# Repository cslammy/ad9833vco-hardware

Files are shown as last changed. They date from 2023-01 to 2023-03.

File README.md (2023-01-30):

# ad9833vco-hardware
Schematics, eagle files etc for AD9833 VCO

I have an ongoing project--building a volt octave VCO using the AD9833 function generator IC.  This repo has current zips of Eagle files, BOMs, gerbers, and PDFs of boards and schematics.

What I post here (1-30-23) works on my bench but could stand some improvement in terms of frequency stability and generally improving the triangle to ramp conversion. The rest of it seems to work. I will update the zips here as I continue to improve this design...

Blog post (which links other posts about this project) is here.
https://audiodiwhy.blogspot.com/2023/01/ad9833-audio-vco-works-work-in-progress.html

Embedded C for this project can be found in this repo: AD9833-VCO

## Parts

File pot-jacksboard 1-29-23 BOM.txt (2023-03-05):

 unt9833VCO pots jacks 1-29-23.sch 

Part       Value         Device                   Package            Description                                       POPULARITY SPICEPREFIX
                    
EUROPWR                  EURO_POWER_HEADERREGULAR EURO_POWER_HEADER  Power Header                                                            
FINE       50K           9MM_SNAP-IN_POT_         9MM_SNAP-IN_POT    9mm vertical snap-in pot, Alpha / Panasonic style                       
FREQ       100k          9MM_SNAP-IN_POT_         9MM_SNAP-IN_POT    9mm vertical snap-in pot, Alpha / Panasonic style                       
                     
MODIN\     THONKICONNNEW THONKICONNNEW            WQP-PJ301M-12_JACK 3.5mm socket for Eurorack modular synths                                
MODLEV     100K          9MM_SNAP-IN_POT_         9MM_SNAP-IN_POT    9mm vertical snap-in pot, Alpha / Panasonic style                       
                
PULSEOUT   THONKICONNNEW THONKICONNNEW            WQP-PJ301M-12_JACK 3.5mm socket for Eurorack modular synths                                
PW-INITIAL 100k          9MM_SNAP-IN_POT_         9MM_SNAP-IN_POT    9mm vertical snap-in pot, Alpha / Panasonic style                       
PWM        100k          9MM_SNAP-IN_POT_         9MM_SNAP-IN_POT    9mm vertical snap-in pot, Alpha / Panasonic style                       
PWMIN      THONKICONNNEW THONKICONNNEW            WQP-PJ301M-12_JACK 3.5mm socket for Eurorack modular synths                                
R1         100K          R-US_0204/7              0204/7             RESISTOR, American symbol                         48         R          
R2         100K          R-US_0207/15             0207/15            RESISTOR, American symbol                         0          R          
R3         100K          R-US_0207/15             0207/15            RESISTOR, American symbol                         0          R          
R4         100ohms       R-US_0207/15             0207/15            RESISTOR, American symbol                         0          R          
R5         100ohms       R-US_0207/15             0207/15            RESISTOR, American symbol                         0          R          
R6         100K          R-US_0207/15             0207/15            RESISTOR, American symbol                         0          R          
R7         100K          R-US_0204/7              0204/7             RESISTOR, American symbol                         48         R          
R8         470K          R-US_0204/7              0204/7             RESISTOR, American symbol                         48         R          
R9         470K          R-US_0204/7              0204/7             RESISTOR, American symbol                         48         R          
RAMPOUT    THONKICONNNEW THONKICONNNEW            WQP-PJ301M-12_JACK 3.5mm socket for Eurorack modular synths                                
                    
TRIOUT     THONKICONNNEW THONKICONNNEW            WQP-PJ301M-12_JACK 3.5mm socket for Eurorack modular synths                                
                  
VOCT       THONKICONNNEW THONKICONNNEW            WQP-PJ301M-12_JACK 3.5mm socket for Eurorack modular synths     

For hardware You will need 100mil (2.54mm) male and female PCB edge connectors
Male: Amphenol 	10129378-920003BLF (get 40 pin edge connector and cut apart what you need)
Female: Adafruit 36-PIN 0.1 FEMALE HEADER- 5PK (digikey 1528-2537-ND)

Also 4/40 phillips screws (I used 3/4" Pan Phillips but most anything about this size will work) with nuts and washers to secure daughterboards to this PCB)

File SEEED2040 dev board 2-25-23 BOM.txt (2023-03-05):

seeed2040 dev board 11-13-22.sch BOM for AD9833 VCO

ADC    MCP3201-CI/P      MCP3201-CI/P      DIP787W46P254L927H533Q8    1-Channel Single ADC SAR 100ksps 12-bit Serial Automotive 8-Pin PDIP Tube  Microchip Technology MCP3201-CI/P DIP-8 Microchip                                                               
C1     .47uF             C-US025-030X050   C025-030X050            CAPACITOR, American symbol                                                                                                                                                                                                                                             C                                      
C4     1nf               C-US025-025X050   C025-025X050            CAPACITOR, American symbol                                                                                                                                                                                                                                              C                                      
C5     .1uF              C-US025-025X050   C025-025X050            CAPACITOR, American symbol                                                                                                                                                                                                                                           C                                      
C6     1nf               C-US025-025X050   C025-025X050            CAPACITOR, American symbol                                                                                                                                                                                                                                          C                                      
C7     1nf               C-US025-025X050   C025-025X050            CAPACITOR, American symbol                                                                                                                                                      
C8     1nf               C-US025-025X050   C025-025X050            CAPACITOR, American symbol                                                                                                                                                                                                                                             C                                      
C9     .1uF              C-US050-025X075   C050-025X075            CAPACITOR, American symbol                                                                                                                                                                                                                                                                                       
C10    .1uF              C-US025-025X050   C025-025X050            CAPACITOR, American symbol                                                                                                                                                                                                                                               C                                      
C11    10uF              CPOL-USE2.5-7     E2,5-7                  POLARIZED CAPACITOR, American symbol                                                                                                                                                                                                                                      C                                      
                                                                                                                                                                                                                                                                                 
D2     Zener 3.3V        ZENER.3           DO41-3                   zener diode                                                                                                                                                                                                                                                                                                                
                                                                                                                                                                                                                                                                                 
D3     10V               ZENER.3           DO41-3                   zener diode                                                                                                                                                                                                                                                                                                                
                                                                                                                                                                                                                                                                                 
IC1-5V L4931             L4931             TO92-                    Voltage regulator                                                                                                                                                                                                                                                                                                                
                                                                                                                                                                                                                                                                               
R1     150K**              R-US_0204/7       0204/7                  RESISTOR, American symbol                                                                                                                                                                                                                                                                                        
R2     150K**              R-US_0204/7       0204/7                  RESISTOR, American symbol                                                                                                                                                                                                                                                                                        
R3     33K**               R-US_0204/7       0204/7                  RESISTOR, American symbol                                                                                                                                                                                                                                                                                        
R4     150K**              R-US_0204/7       0204/7                  RESISTOR, American symbol                                                                                                                                                                                                                                                                                        
R5     100K              R-US_0204/7       0204/7                  RESISTOR, American symbol                                                                                                                                                                                                                                                                                        
R6     33K               R-US_0204/7       0204/7                  RESISTOR, American symbol                                                                                                                                                                                                                                                                                        
R7     1.2K              R-US_0204/7       0204/7                  RESISTOR, American symbol                                                                                                                                                                                                                                                                                        
R8     47K               R-US_0204/7       0204/7                  RESISTOR, American symbol                                                                                                                                                                                                                                                                                        
R9     33K**               R-US_0204/7       0204/7                  RESISTOR, American symbol                                                                                                                                                                                                                                                                                        
R10    100K*              R-US_0204/7       0204/7                  RESISTOR, American symbol                                                                                                                                                                                                                                                                                        
R11    100K*              R-US_0204/7       0204/7                  RESISTOR, American symbol                                                                                                                                                                                                                                                                                        
R12    100K*              R-US_0204/7       0204/7                  RESISTOR, American symbol                                                                                                                                                                                                                                                                                        
R13    33K**               R-US_0204/7       0204/7                  RESISTOR, American symbol                                                                                                                                                                                                                                                                                        
R14    2701%             R-US_0204/7       0204/7                  RESISTOR, American symbol                                                                                                                                                                                                                                              
NOTES on resistors for AD9833 build:
* you can use any resistor value here--or a jumper wire.                                          
** this resistor is not needed for AD9833 build (since given op amp stage has both inputs grounded)--you can omit this resistor if you are using this buffer to build an RP2040-AD9833 audio volt/octave VCO
                                                                                                                                                                                                                                                                                 
SEEDY1 SEEED_XIAO_RP2040 SEEED_XIAO_RP2040 14PIN700MIL             RP2040 Development board                                                                                                                                                                                                                                                                                                                    
T1     50K               R-TRIMMT93YA      RTRIMT93YA              Trimm resistor                                                              
                                                                                                                                                                                               
U1     MCP6004-DIP       MCP6004-DIP       DIL14                   MCP6004 RAIL TO RAIL QUAD OP AMP

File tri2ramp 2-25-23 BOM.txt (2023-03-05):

 
tri to ramp-pls 2-25-23.sch 

Part    Value   Device          Package       Description                          POPULARITY SPICEPREFIX
        1                     
C1      2.2uF   CPOL-USE5-4     E5-4          POLARIZED CAPACITOR, American symbol                       
C2      .0022uF C-US050-030X075 C050-030X075  CAPACITOR, American symbol           5          C          
C3      .0022uF C-US050-035X075 C050-035X075  CAPACITOR, American symbol           0          C          
C4      .1uF    C-US025-025X050 C025-025X050  CAPACITOR, American symbol           0          C          
C5      .1uF    C-US025-025X050 C025-025X050  CAPACITOR, American symbol           0          C          
C6      .1uF    C-US025-025X050 C025-025X050  CAPACITOR, American symbol           0          C          
C7      .1uF    C-US025-025X050 C025-025X050  CAPACITOR, American symbol           0          C          
C8      10uF    CPOL-USE5-4     E5-4          POLARIZED CAPACITOR, American symbol                       
C9      .01uF   C-US050-035X075 C050-035X075  CAPACITOR, American symbol           0          C          
D1      5V      ZENER.3         DO41-3        3V Zener                                                           
                  
IC1     TL084D  TL084D          SO14          OP AMP                               4                     
IC2     CA3140N CA3140N         DIL08         OP AMP                               3                     
IC3     TL081D  TL081D          SO08          OP AMP                                                     
IC4     7805L   ADAFRUIT_7805L  ADAFRUIT_TO92 Positive VOLTAGE REGULATOR                                 
         1                     
Q1      2N7000  2N7000          TO92-         MOSFET                                                          
R1      10K 1%  R-US_0204/7     0204/7        RESISTOR, American symbol                                  
R2      27K     R-US_0204/7     0204/7        RESISTOR, American symbol                                  
R3      20K     R-US_0204/7     0204/7        RESISTOR, American symbol                                  
R4      20K     R-US_0204/7     0204/7        RESISTOR, American symbol                                  
R5      200K    R-US_0204/7     0204/7        RESISTOR, American symbol                                  
R6      1K      R-US_0204/7     0204/7        RESISTOR, American symbol                                  
R7      1K      R-US_0204/7     0204/7        RESISTOR, American symbol                                  
R8      100K    R-US_0204/7     0204/7        RESISTOR, American symbol                                  
R9      100K    R-US_0204/7     0204/7        RESISTOR, American symbol                                  
R10     100K    R-US_0204/7     0204/7        RESISTOR, American symbol                                  
R11     20K     R-US_0204/7     0204/7        RESISTOR, American symbol                                  
R12     1K      R-US_0204/7     0204/7        RESISTOR, American symbol                                  
R13     180     R-US_0204/7     0204/7        RESISTOR, American symbol                                  
R14     1K      R-US_0204/7     0204/7        RESISTOR, American symbol                                  
R15     10K     R-US_0204/7     0204/7        RESISTOR, American symbol                                  
R16     20K 1%  R-US_0204/7     0204/7        RESISTOR, American symbol                                  
R17     100K 1% R-US_0204/7     0204/7        RESISTOR, American symbol                                  
R18     50K 1%  R-US_0204/7     0204/7        RESISTOR, American symbol                                  
R19     20K     R-US_0204/7     0204/7        RESISTOR, American symbol                                  

Breakout Board:
Project requires AD9833 Sig Generator with the following pinout:
VCC
DGND
SDATA
SCLK
FSYNC
AGND
OUT

here is one that works (the one I used)
NOYITO AD9833 Programmable Microprocessor Serial Interface Module Sine Square Wave DDS Signal Generator
https://www.amazon.com/NOYITO-Programmable-Microprocessor-Interface-Generator/dp/B07HFRFMPM
There are many other vendors selling boards just like this on Aliexpress, Ebay etc.
But!! Check to make sure what you buy has the pinout above.

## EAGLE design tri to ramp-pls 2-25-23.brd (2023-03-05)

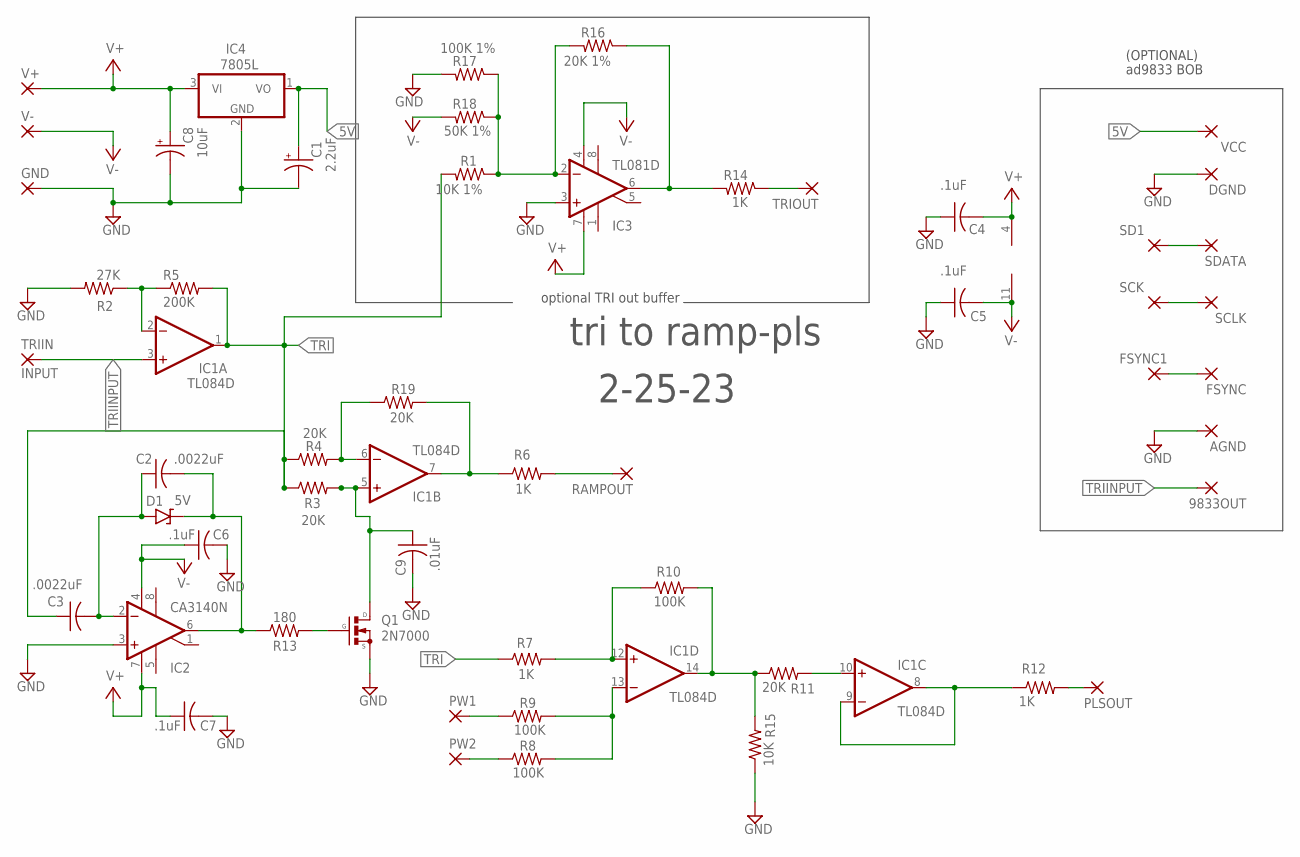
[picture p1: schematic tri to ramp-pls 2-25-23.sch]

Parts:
9833OUT: WIREPAD1,6/0,8; 1,6/0,8
AGND: WIREPAD1,6/0,8; 1,6/0,8
C1: 2.2uF; E5-4
C2: .0022uF; C050-030X075
C3: .0022uF; C050-035X075
C4, C5, C6, C7: .1uF; C025-025X050
C8: 10uF; E5-4
C9: .01uF; C050-035X075
D1: 5V; DO41-3
DGND: WIREPAD1,6/0,8; 1,6/0,8
FSYNC, FSYNC1: WIREPAD1,6/0,8; 1,6/0,8
GND: WIREPAD1,6/0,8; 1,6/0,8
IC1: TL084D; SO14
IC2: CA3140N; DIL08
IC3: TL081D; SO08
IC4: 7805L; ADAFRUIT_TO92
PLSOUT: WIREPAD1,6/0,8; 1,6/0,8
PW1, PW2: WIREPAD1,6/0,8; 1,6/0,8
Q1: 2N7000; TO92-
R1: 10K 1%; 0204/7
R2: 27K; 0204/7
R3, R4, R11, R19: 20K; 0204/7
R5: 200K; 0204/7
R6, R7, R12, R14: 1K; 0204/7
R8, R9, R10: 100K; 0204/7
R13: 180; 0204/7
R15: 10K; 0204/7
R16: 20K 1%; 0204/7
R17: 100K 1%; 0204/7
R18: 50K 1%; 0204/7
RAMPOUT: WIREPAD1,6/0,8; 1,6/0,8
SCK: WIREPAD1,6/0,8; 1,6/0,8
SCLK: WIREPAD1,6/0,8; 1,6/0,8
SD1: WIREPAD1,6/0,8; 1,6/0,8
SDATA: WIREPAD1,6/0,8; 1,6/0,8
TRIIN: INPUT; 1,6/0,8
TRIOUT: WIREPAD1,6/0,8; 1,6/0,8
V+: WIREPAD1,6/0,8; 1,6/0,8
V-: WIREPAD1,6/0,8; 1,6/0,8
VCC: WIREPAD1,6/0,8; 1,6/0,8

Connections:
5V: C1.+, IC4.1 (VO), VCC.1
GND: AGND.1, C1.-, C4.1, C5.1, C6.2, C7.2, C8.-, C9.2, DGND.1, GND.1, IC2.3 (+IN), IC3.3 (+IN), IC4.2 (GND), Q1.3 (S), R2.2, R15.1, R17.2
unnamed: IC1.2 (-IN), R2.1, R5.1
unnamed: PW1.1, R9.1
unnamed: SD1.1, SDATA.1
unnamed: IC1.12 (+IN), R7.2, R10.1
unnamed: IC1.6 (-IN), R4.2, R19.1
unnamed: C9.1, IC1.5 (+IN), Q1.1 (D), R3.2
unnamed: C2.1, C3.2, D1.A, IC2.2 (-IN)
unnamed: IC1.7 (OUT), R6.1, R19.2
unnamed: C2.2, D1.C, IC2.6 (OUT), R13.1
unnamed: Q1.2 (G), R13.2
unnamed: IC1.14 (OUT), R10.2, R11.1, R15.2
unnamed: R6.2, RAMPOUT.1
unnamed: IC1.10 (+IN), R11.2
unnamed: IC1.8 (OUT), IC1.9 (-IN), R12.1
unnamed: PLSOUT.1, R12.2
unnamed: IC1.13 (-IN), R8.2, R9.2
unnamed: IC3.2 (-IN), R1.1, R16.2, R17.1, R18.1
unnamed: PW2.1, R8.1
unnamed: R14.1, TRIOUT.1
unnamed: SCK.1, SCLK.1
unnamed: FSYNC.1, FSYNC1.1
unnamed: IC3.6 (OUT), R14.2, R16.1
TRI: C3.1, IC1.1 (OUT), R1.2, R3.1, R4.1, R5.2, R7.1
TRIINPUT: 9833OUT.1, IC1.3 (+IN), TRIIN.1
V+: C4.2, C7.1, C8.+, IC1.4 (V+), IC2.7 (V+), IC3.7 (V+), IC4.3 (VI), V+.1
V-: C5.2, C6.1, IC1.11 (V-), IC2.4 (V-), IC3.4 (V-), R18.2, V-.1

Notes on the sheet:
tri to ramp-pls
2-25-23
optional TRI out buffer
ad9833 BOB
(OPTIONAL)

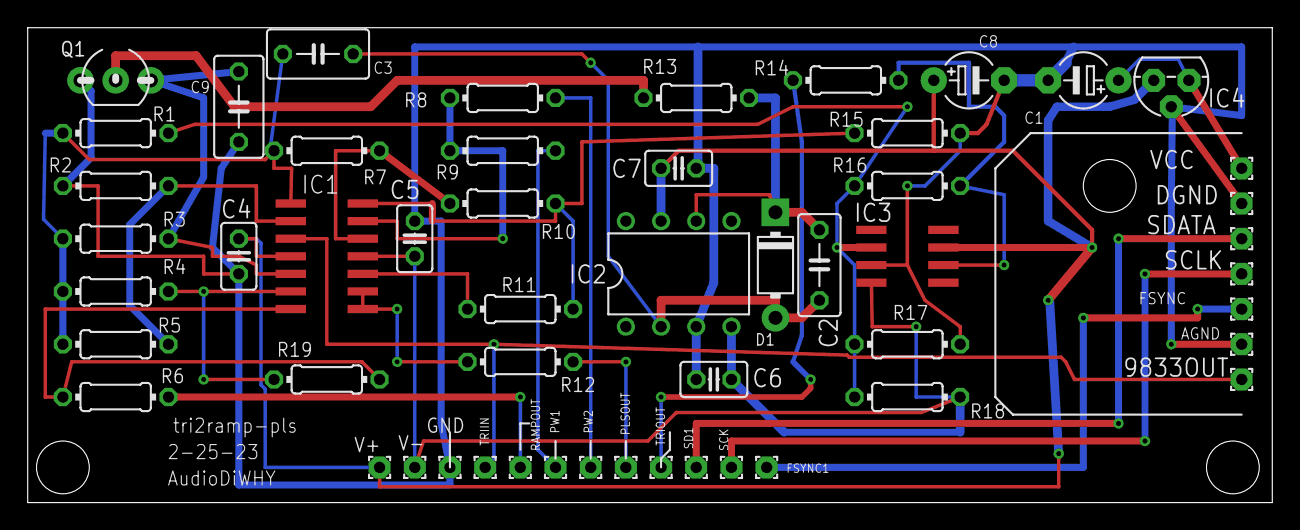
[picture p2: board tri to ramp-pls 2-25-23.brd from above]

Board: 2 copper layers, 89.8 x 34.3 mm, 53 parts (0 on the bottom side), 28 nets.

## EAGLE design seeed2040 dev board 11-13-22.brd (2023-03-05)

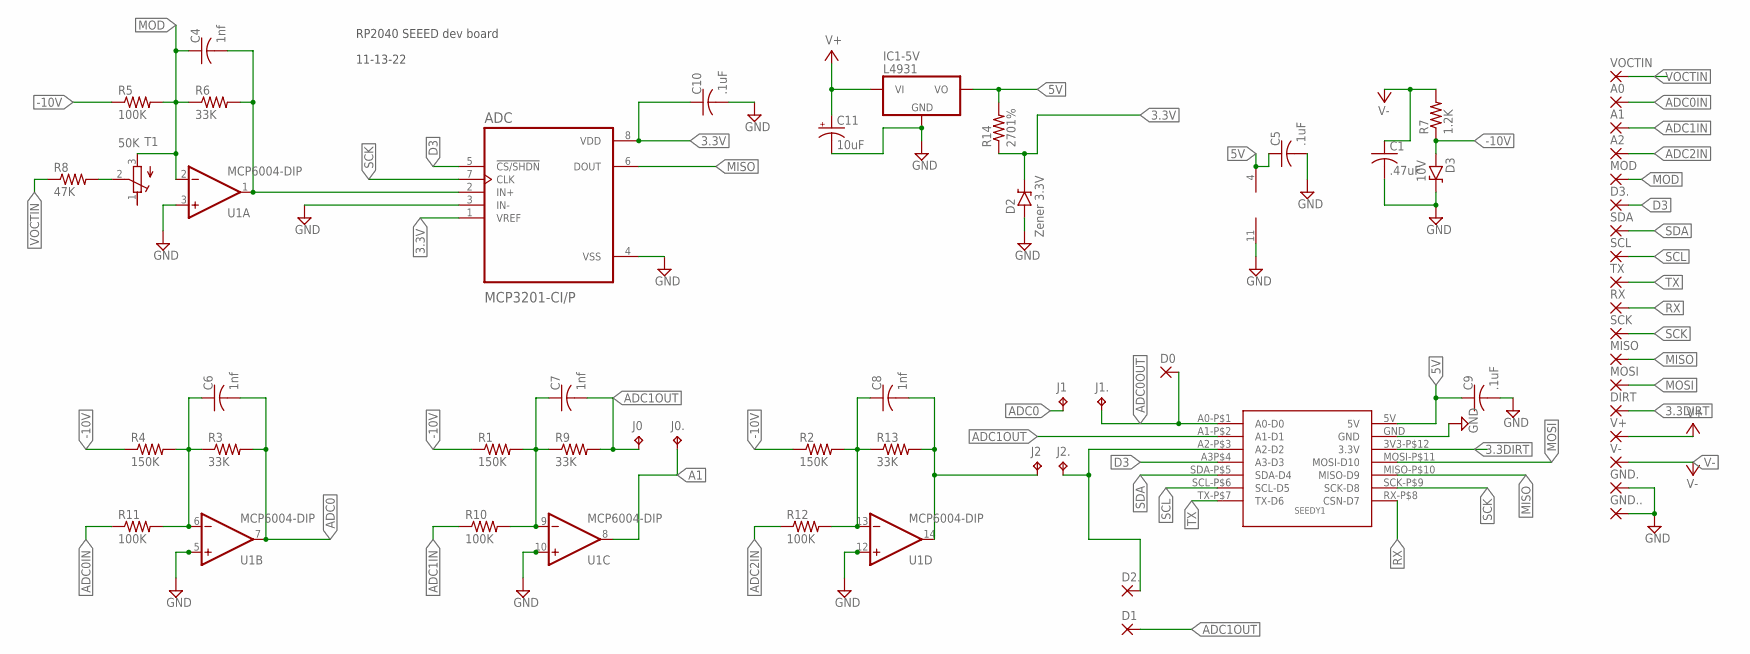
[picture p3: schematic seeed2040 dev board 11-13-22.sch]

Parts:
A0, A1, A2: WIREPAD1,6/0,9; 1,6/0,9
ADC: MCP3201-CI/P; DIP787W46P254L927H533Q8
C1: .47uF; C025-030X050
C4, C6, C7, C8: 1nf; C025-025X050
C5, C10: .1uF; C025-025X050
C9: .1uF; C050-025X075
C11: 10uF; E2,5-7
D0, D1, D2., D3.: WIREPAD1,6/0,9; 1,6/0,9
D2: Zener 3.3V; DO41-3
D3: 10V; DO41-3
DIRT: WIREPAD1,6/0,9; 1,6/0,9
GND., GND..: WIREPAD1,6/0,9; 1,6/0,9
IC1-5V: L4931; TO92-
J0, J0., J1, J1., J2, J2.: TPPAD1-13; P1-13
MISO: WIREPAD1,6/0,9; 1,6/0,9
MOD: WIREPAD1,6/0,9; 1,6/0,9
MOSI: WIREPAD1,6/0,9; 1,6/0,9
R1, R2, R4: 150K; 0204/7
R3, R6, R9, R13: 33K; 0204/7
R5, R10, R11, R12: 100K; 0204/7
R7: 1.2K; 0204/7
R8: 47K; 0204/7
R14: 2701%; 0204/7
RX: WIREPAD1,6/0,9; 1,6/0,9
SCK: WIREPAD1,6/0,9; 1,6/0,9
SCL: WIREPAD1,6/0,9; 1,6/0,9
SDA: WIREPAD1,6/0,9; 1,6/0,9
SEEDY1: SEEED_XIAO_RP2040; 14PIN700MIL
T1: 50K; RTRIMT93YA
TX: WIREPAD1,6/0,9; 1,6/0,9
U1: MCP6004-DIP; DIL14
V+: WIREPAD1,6/0,9; 1,6/0,9
V-: WIREPAD1,6/0,9; 1,6/0,9
VOCTIN: WIREPAD1,6/0,9; 1,6/0,9

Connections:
3.3DIRT: DIRT.1, SEEDY1.3V3-P$12 (3.3V)
3.3V: ADC.1 (VREF), ADC.8 (VDD), C10.1, D2.C, R14.1
5V: C5.1, C9.1, IC1-5V.3 (VO), R14.2, SEEDY1.5V, U1.4 (V+)
-10V: D3.A, R1.1, R2.1, R4.1, R5.1, R7.1
A1: J0..TP, U1.8 (OUT)
ADC0: C6.2, J1.TP, R3.2, U1.7 (OUT)
ADC0IN: A0.1, R11.1
ADC0OUT: D0.1, J1..TP, SEEDY1.A0-P$1 (A0-D0)
ADC1IN: A1.1, R10.1
ADC1OUT: C7.2, D1.1, J0.TP, R9.2, SEEDY1.A1-P$2 (A1-D1)
ADC2IN: A2.1, R12.1
ADC2OUT: C8.2, J2.TP, R13.2, U1.14 (OUT)
D3: ADC.5 (!CS/SHDN), D3..1, SEEDY1.A3P$4 (A3-D3)
GND: ADC.3 (IN-), ADC.4 (VSS), C1.2, C5.2, C9.2, C10.2, C11.-, D2.A, D3.C, GND..1, GND...1, IC1-5V.2 (GND), SEEDY1.GND, U1.3 (+IN), U1.5 (+IN), U1.10 (+IN), U1.11 (V-), U1.12 (+IN)
MISO: ADC.6 (DOUT), MISO.1, SEEDY1.MISO-P$10 (MISO-D9)
MOD: C4.1, MOD.1, R5.2, R6.1, T1.3 (A), U1.2 (-IN)
MOSI: MOSI.1, SEEDY1.MOSI-P$11 (MOSI-D10)
unnamed: C6.1, R3.1, R4.2, R11.2, U1.6 (-IN)
unnamed: C7.1, R1.2, R9.1, R10.2, U1.9 (-IN)
unnamed: R8.2, T1.2 (S)
unnamed: C8.1, R2.2, R12.2, R13.1, U1.13 (-IN)
unnamed: D2..1, J2..TP, SEEDY1.A2-P$3 (A2-D2)
RX: RX.1, SEEDY1.RX-P$8 (CSN-D7)
SCK: ADC.7 (CLK), SCK.1, SEEDY1.SCK-P$9 (SCK-D8)
SCL: SCL.1, SEEDY1.SCL-P$6 (SCL-D5)
SDA: SDA.1, SEEDY1.SDA-P$5 (SDA-D4)
TX: SEEDY1.TX-P$7 (TX-D6), TX.1
V+: C11.+, IC1-5V.1 (VI), V+.1
V-: C1.1, R7.2, V-.1
VOCTIN: R8.1, VOCTIN.1
VOCTOUT: ADC.2 (IN+), C4.2, R6.2, U1.1 (OUT)

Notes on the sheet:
RP2040 SEEED dev board
11-13-22

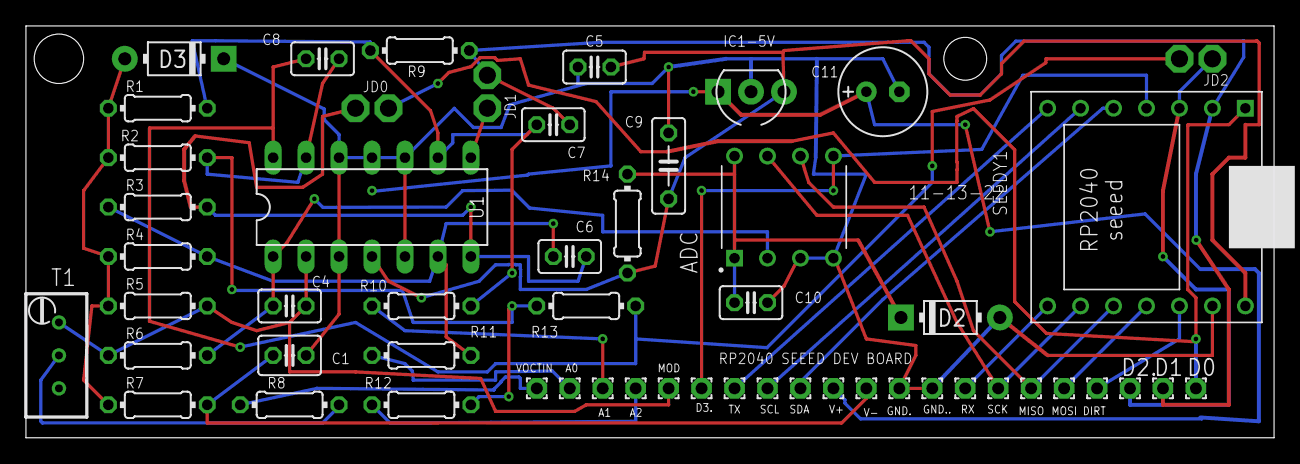
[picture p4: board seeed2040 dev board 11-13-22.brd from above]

Board: 2 copper layers, 96.2 x 31.7 mm, 57 parts (0 on the bottom side), 31 nets.

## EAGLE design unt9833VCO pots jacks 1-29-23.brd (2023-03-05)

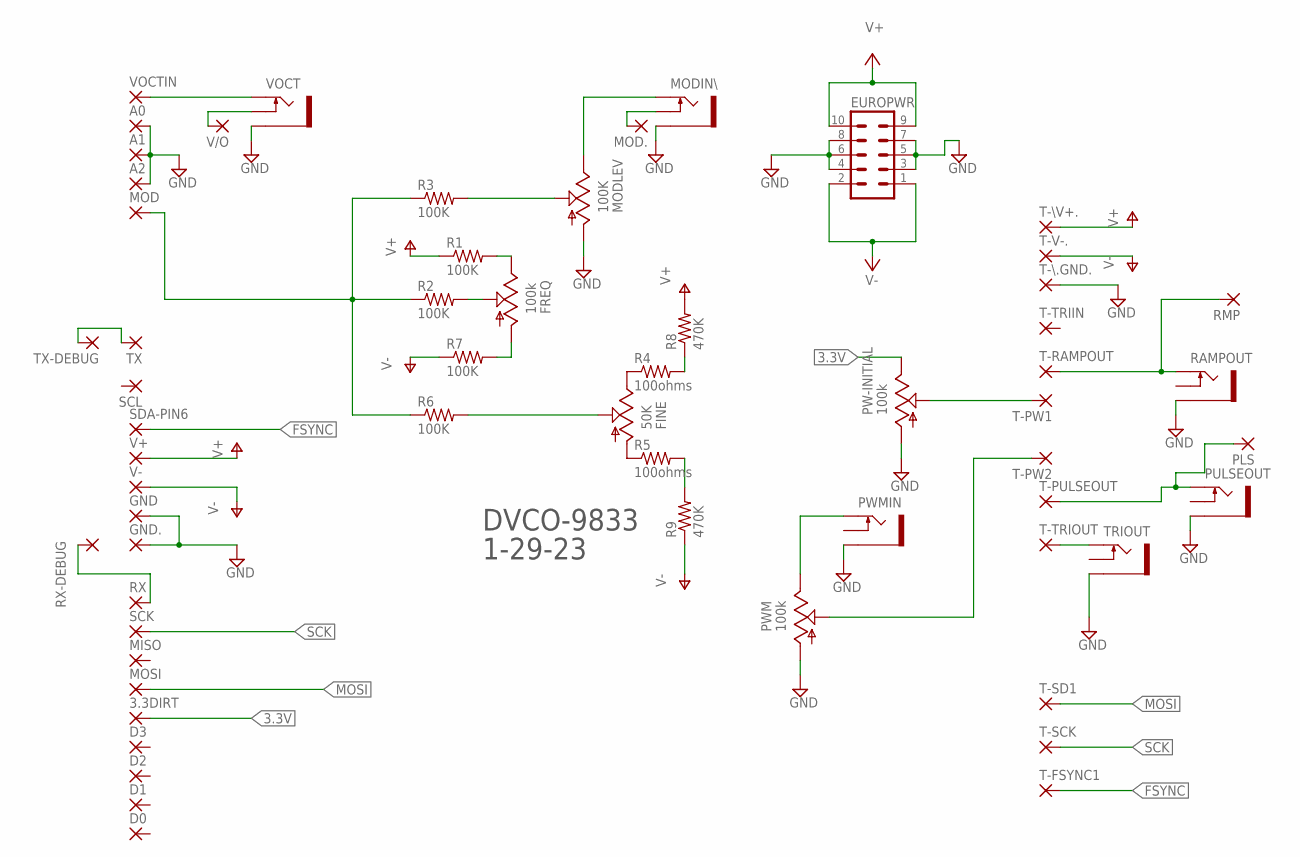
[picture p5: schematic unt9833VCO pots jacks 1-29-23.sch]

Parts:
3.3DIRT: WIREPAD1,6/0,9; 1,6/0,9
A0, A1, A2: WIREPAD1,6/0,9; 1,6/0,9
D0, D1, D2, D3: WIREPAD1,6/0,9; 1,6/0,9
EUROPWR: EURO_POWER_HEADERREGULAR; EURO_POWER_HEADER
FINE: 50K; 9MM_SNAP-IN_POT
FREQ: 100k; 9MM_SNAP-IN_POT
GND, GND.: WIREPAD1,6/0,9; 1,6/0,9
MISO: WIREPAD1,6/0,9; 1,6/0,9
MOD, MOD.: WIREPAD1,6/0,9; 1,6/0,9
MODIN\: THONKICONNNEW; WQP-PJ301M-12_JACK
MODLEV: 100K; 9MM_SNAP-IN_POT
MOSI: WIREPAD1,6/0,9; 1,6/0,9
PLS: WIREPAD1,6/0,9; 1,6/0,9
PULSEOUT: THONKICONNNEW; WQP-PJ301M-12_JACK
PW-INITIAL: 100k; 9MM_SNAP-IN_POT
PWM: 100k; 9MM_SNAP-IN_POT
PWMIN: THONKICONNNEW; WQP-PJ301M-12_JACK
R1, R7: 100K; 0204/7
R2, R3, R6: 100K; 0207/15
R4, R5: 100ohms; 0207/15
R8, R9: 470K; 0204/7
RAMPOUT: THONKICONNNEW; WQP-PJ301M-12_JACK
RMP: WIREPAD1,6/0,9; 1,6/0,9
RX: WIREPAD1,6/0,9; 1,6/0,9
RX-DEBUG: WIREPAD1,6/0,9; 1,6/0,9
SCK: WIREPAD1,6/0,9; 1,6/0,9
SCL: WIREPAD1,6/0,9; 1,6/0,9
SDA-PIN6: WIREPAD1,6/0,9; 1,6/0,9
T-FSYNC1: WIREPAD1,6/0,9; 1,6/0,9
T-PULSEOUT: WIREPAD1,6/0,9; 1,6/0,9
T-PW1, T-PW2: WIREPAD1,6/0,9; 1,6/0,9
T-RAMPOUT: WIREPAD1,6/0,9; 1,6/0,9
T-SCK: WIREPAD1,6/0,9; 1,6/0,9
T-SD1: WIREPAD1,6/0,9; 1,6/0,9
T-TRIIN: WIREPAD1,6/0,9; 1,6/0,9
T-TRIOUT: WIREPAD1,6/0,9; 1,6/0,9
T-V-.: WIREPAD1,6/0,9; 1,6/0,9
T-\.GND.: WIREPAD1,6/0,9; 1,6/0,9
T-\V+.: WIREPAD1,6/0,9; 1,6/0,9
TRIOUT: THONKICONNNEW; WQP-PJ301M-12_JACK
TX: WIREPAD1,6/0,9; 1,6/0,9
TX-DEBUG: WIREPAD1,6/0,9; 1,6/0,9
V+: WIREPAD1,6/0,9; 1,6/0,9
V-: WIREPAD1,6/0,9; 1,6/0,9
V/O: WIREPAD1,6/0,9; 1,6/0,9
VOCT: THONKICONNNEW; WQP-PJ301M-12_JACK
VOCTIN: WIREPAD1,6/0,9; 1,6/0,9

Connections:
3.3V: 3.3DIRT.1, PW-INITIAL.3 (E)
FSYNC: SDA-PIN6.1, T-FSYNC1.1
GND: A0.1, A1.1, A2.1, EUROPWR.3, EUROPWR.4, EUROPWR.5, EUROPWR.6, EUROPWR.7, EUROPWR.8, GND.1, GND..1, MODIN\.P$3_SLEEVE (SLEEVE), MODLEV.1 (A), PULSEOUT.P$3_SLEEVE (SLEEVE), PW-INITIAL.1 (A), PWM.1 (A), PWMIN.P$3_SLEEVE (SLEEVE), RAMPOUT.P$3_SLEEVE (SLEEVE), T-\.GND..1, TRIOUT.P$3_SLEEVE (SLEEVE), VOCT.P$3_SLEEVE (SLEEVE)
MOSI: MOSI.1, T-SD1.1
unnamed: VOCT.P$1_TIP (TIP), VOCTIN.1
unnamed: MOD.1, R2.1, R3.1, R6.1
unnamed: MODIN\.P$1_TIP (TIP), MODLEV.3 (E)
unnamed: MOD..1, MODIN\.P$2_SWITCH (SWITCH)
unnamed: MODLEV.2 (S), R3.2
unnamed: FINE.3 (E), R4.1
unnamed: FINE.1 (A), R5.1
unnamed: FINE.2 (S), R6.2
unnamed: FREQ.2 (S), R2.2
unnamed: PLS.1, PULSEOUT.P$1_TIP (TIP), T-PULSEOUT.1
unnamed: T-TRIOUT.1, TRIOUT.P$1_TIP (TIP)
unnamed: FREQ.3 (E), R1.2
unnamed: PW-INITIAL.2 (S), T-PW1.1
unnamed: PWM.2 (S), T-PW2.1
unnamed: PWM.3 (E), PWMIN.P$1_TIP (TIP)
unnamed: V/O.1, VOCT.P$2_SWITCH (SWITCH)
unnamed: TX.1, TX-DEBUG.1
unnamed: FREQ.1 (A), R7.2
unnamed: RX.1, RX-DEBUG.1
unnamed: R5.2, R9.2
unnamed: R4.2, R8.1
RMP>: RAMPOUT.P$1_TIP (TIP), RMP.1, T-RAMPOUT.1
SCK: SCK.1, T-SCK.1
V+: EUROPWR.9, EUROPWR.10, R1.1, R8.2, T-\V+..1, V+.1
V-: EUROPWR.1, EUROPWR.2, R7.1, R9.1, T-V-..1, V-.1

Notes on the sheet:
DVCO-9833
1-29-23

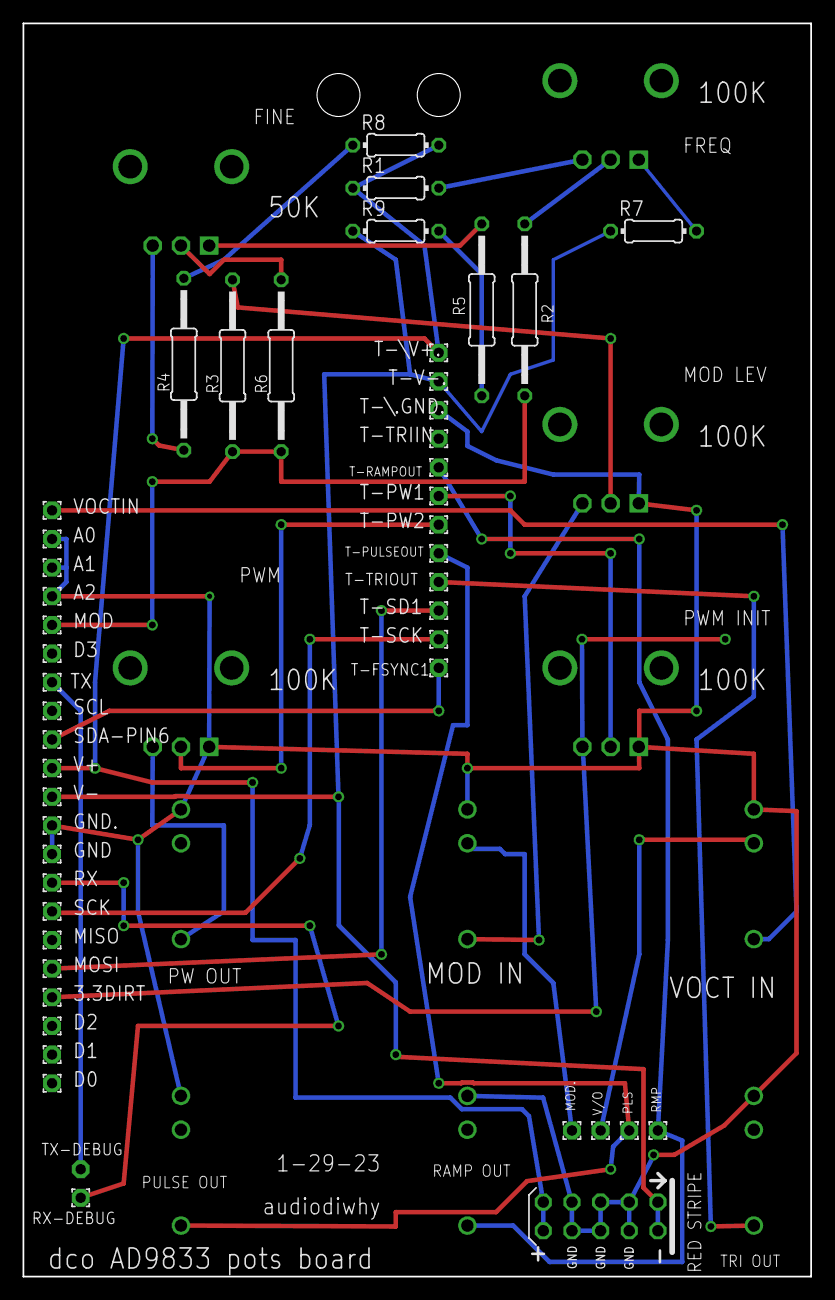
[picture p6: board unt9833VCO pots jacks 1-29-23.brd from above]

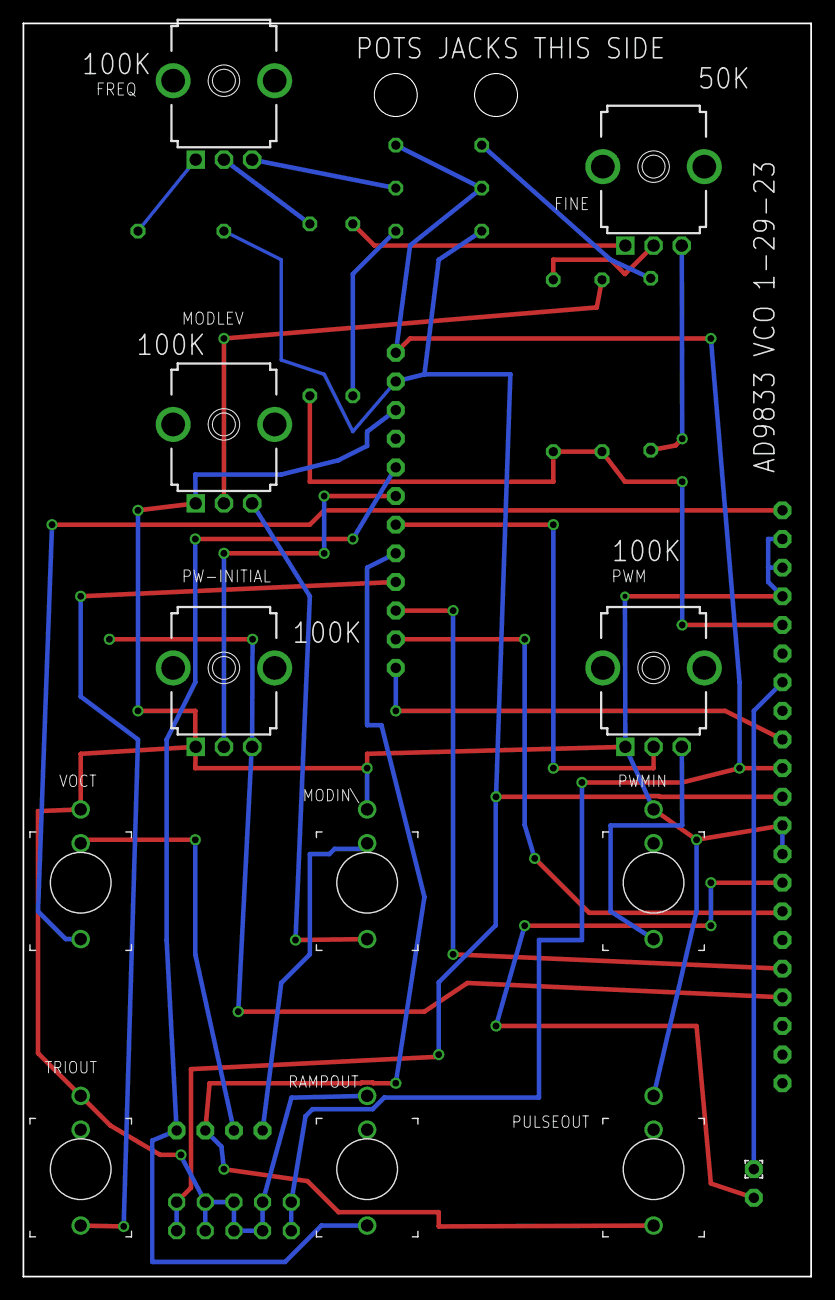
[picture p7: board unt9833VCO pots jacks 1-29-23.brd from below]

Board: 2 copper layers, 69.8 x 111.1 mm, 60 parts (12 on the bottom side), 29 nets.

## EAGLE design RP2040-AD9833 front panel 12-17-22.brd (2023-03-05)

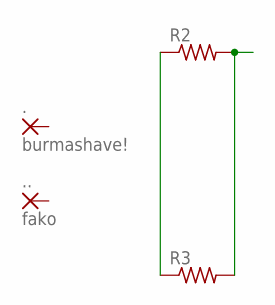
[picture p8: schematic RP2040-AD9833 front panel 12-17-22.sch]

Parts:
.: burmashave!; WIREPAD_SMD1,27-2,54
..: fako; WIREPAD_SMD1,27-2,54
R2, R3: R-US_MELF0207R; MINI_MELF-0207R

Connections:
unnamed: R2.1, R3.1
unnamed: R2.2, R3.2

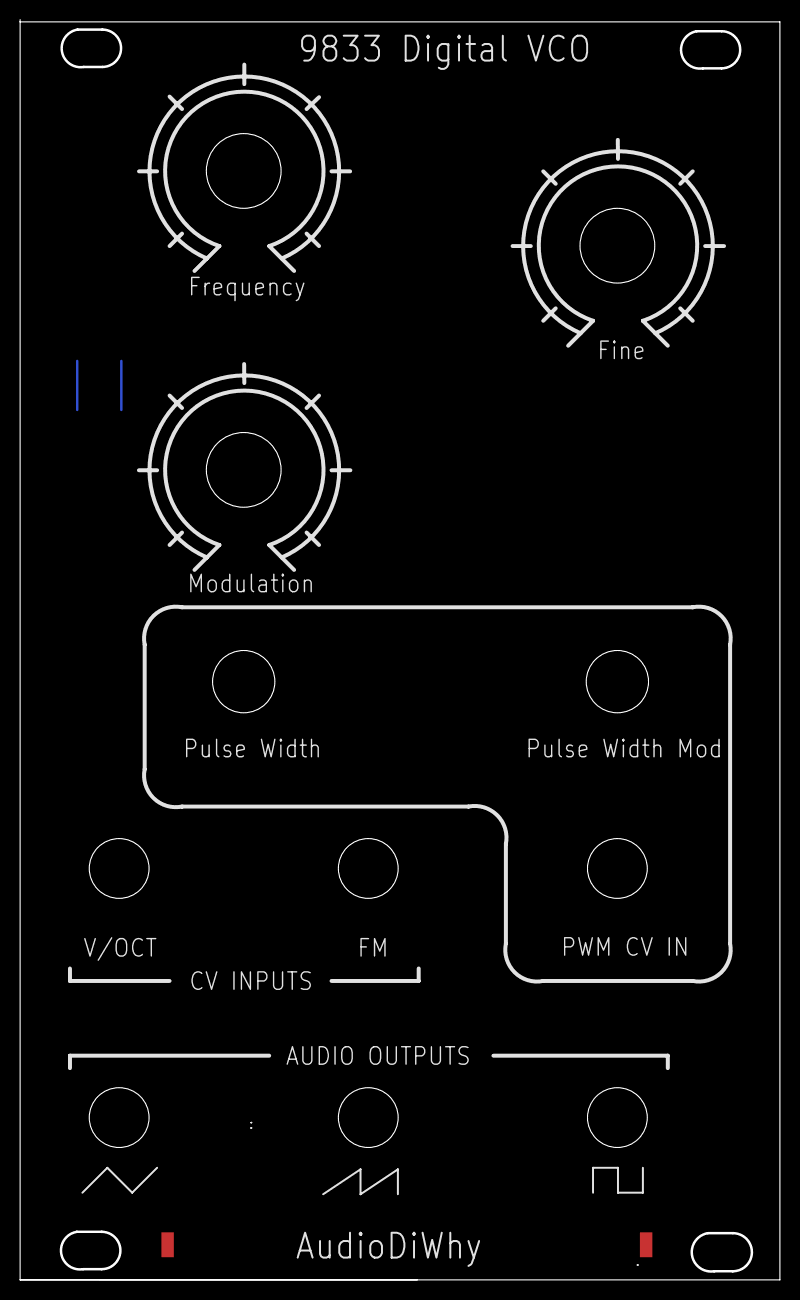
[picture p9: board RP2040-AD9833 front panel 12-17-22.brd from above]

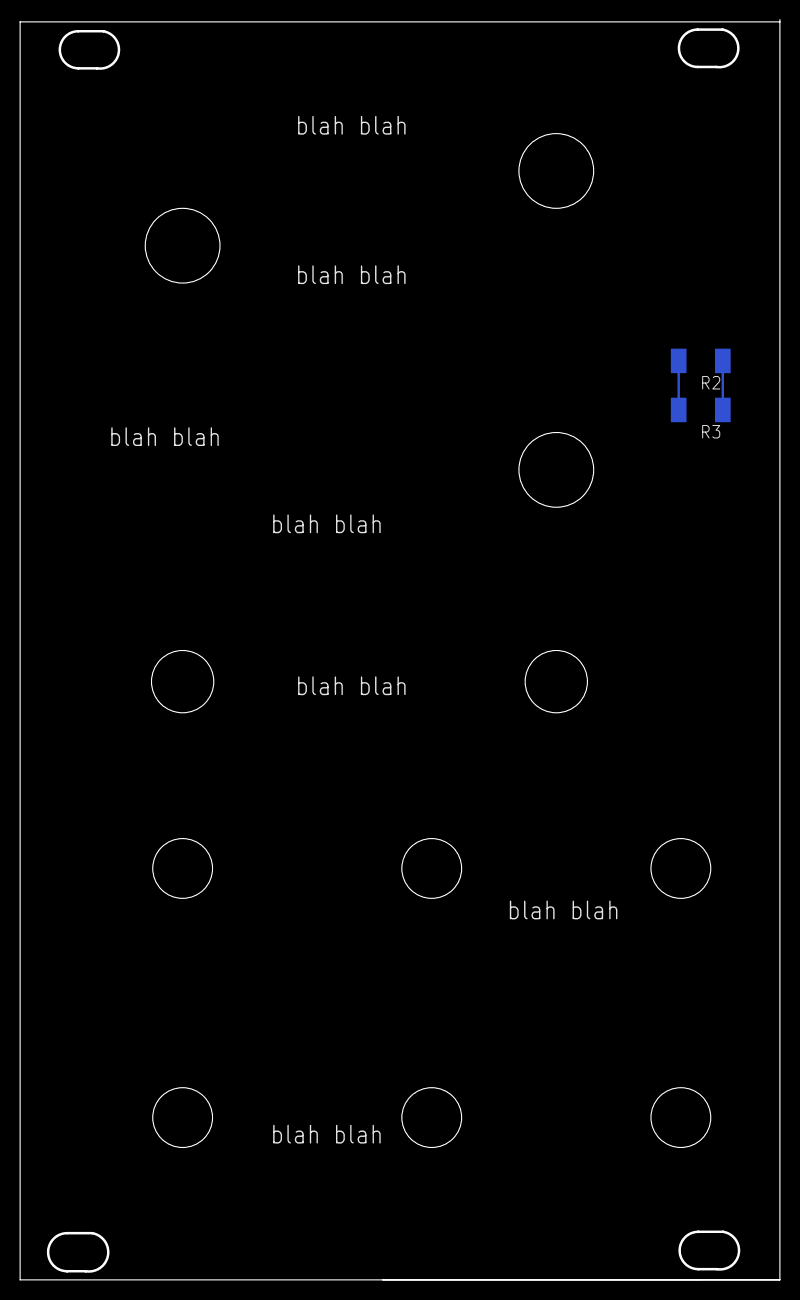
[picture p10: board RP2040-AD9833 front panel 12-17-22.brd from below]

Board: 2 copper layers, 77.5 x 128.3 mm, 4 parts (2 on the bottom side), 2 nets.
